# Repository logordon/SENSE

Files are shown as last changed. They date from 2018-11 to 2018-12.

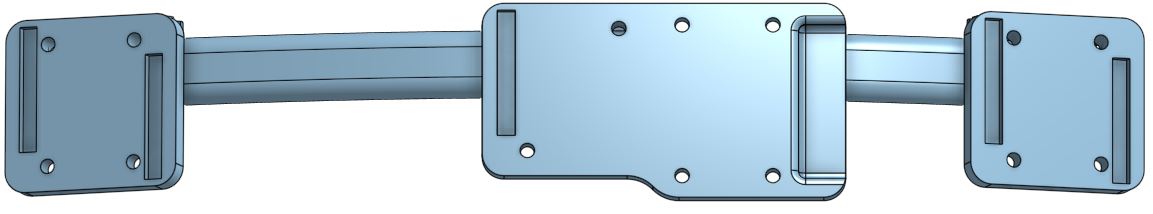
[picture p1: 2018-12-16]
Project Images/sensor_view_front.JPG

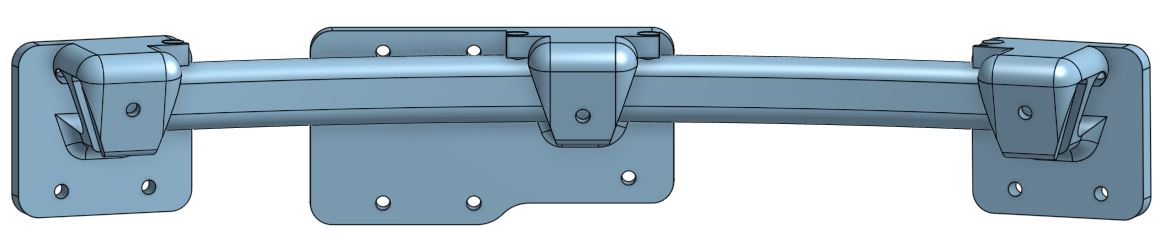
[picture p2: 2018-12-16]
Project Images/sensor_view_back.JPG

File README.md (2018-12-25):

# SENSE: Modernizing Blind Navigational Tools
Sense Glasses

# Welcome
Welcome and thank you for checking out _Project SENSE_. For more information on how this project was done **please visit the project [Wiki](https://github.com/logordon/SENSE/wiki)**. 

_Thank you and happy prototyping_ - Gordon Lo

# Project Overview Documents
**SENSE** was the 2018 Fall Northeastern Capstone 2nd place winner. Listed below are documents that will give you an overview of what _Project SENSE_ is about.
* [Project Presentation](https://github.com/logordon/SENSE/blob/master/Presentation%20Documents/SENSE%20Final%20Presentation.pdf)
* [Abstract](https://github.com/logordon/SENSE/blob/master/Presentation%20Documents/Abstract.pdf)

# Last Update
December 24, 2018 - Gordon Lo

# Special Thanks
Special thanks to [Arjun Vinod](https://github.com/arjun7965) for his extensive knowledge on hardware and software integration and my good friend Lek Kai Ming for modeling.

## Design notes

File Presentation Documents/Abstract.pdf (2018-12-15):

### SENSE: Modern Navigational Tools for the Blind

Team Members: Gordon Lo, Dixon Jin, Devin Touba, Imtiaz Hssan, Branden Bielot Advisor: Professor Bahram Shafai

Abstract
There has still not been any major technological advancement that comes remotely close to replacing the cane blind people use to interact with the world around them. Many of the modern blind aids that enable people to see, cater towards people with partial blindness and not to people who are totally blind. Data collected by the National Braille Press states that 0.45% or 1.5M of the US population are blind and thus SENSE aims to cater towards the needs of the totally blind and modernize the tools they use to navigate and interact with the world around them.

Two-devices: the SENSE glasses and the SENSE belt, capture and interpret data collected from the ultrasonic sensors and output haptic and audio feedback based on proximity to an obstacle. Utilizing a non-invasive technique called sensory substitution, we can bypass the loss of a sense (sight) by feeding its information through another channel (audio and touch). Leveraging this technique, we developed a low-cost vibratory belt and bone conducting audio glasses to allow blind people to perceive spatial awareness through small vibrations on their waist and audio alerts from bone conduction headphones.

Both SENSE devices compute and process data through individual raspberry pi zeroes. The SENSE glasses algorithm is designed based on the assumption that we dynamically scan areas of interest before and after sensing an obstacle. 3 ultrasonic sensors mounted on a pair of glasses gives the user free range to scan 3 meters ahead wherever they think may be an obstacle based on their instincts and other senses. Sensors on all SENSE devices are able to constantly and simultaneously take readings at the same time. This built-in functionality enables us to further divide the combined 75° sensor arc, into 5 smaller subsections: left, center-left, center, center-right and right. Depending on where the object within the 75° arc, audio cues will tell the user which sector the obstacle is in and how far away the obstacle is. Since our sensors are accurate till 3 meters, 3 beeps will represent 1 meter, 2 beeps will represent 2 meters and 1 beep will represent 1 meter. The glasses will output “center-left, beep, beep” when an obstacle is 2 meters away and in the center-left sector.

The SENSE belt, on the other hand, supplements the glasses by acting as a stationary 180° frontal guard that constantly scans for obstacles. Sensors are designed to point at a 30° downward angle to not only scan for obstacles at waist height but also sudden changes in elevation, such as stairs. With two sensors covering the outer sides, 270° and 90°, and another two sensors facing 315° and 45°, the SENSE belt guards againsts obstacles and changes in elevation within the user’s front facing 180° arc.

The SENSE system mimics how we perceive sight and movement. When utilized in conjunction with one another, the SENSE belt and glasses provides a full frontal obstacle avoidance system that allows blind people to scan and probe areas around them. With more research into more precise sensors and improvements to our algorithm, the SENSE system will replace the use of a cane.

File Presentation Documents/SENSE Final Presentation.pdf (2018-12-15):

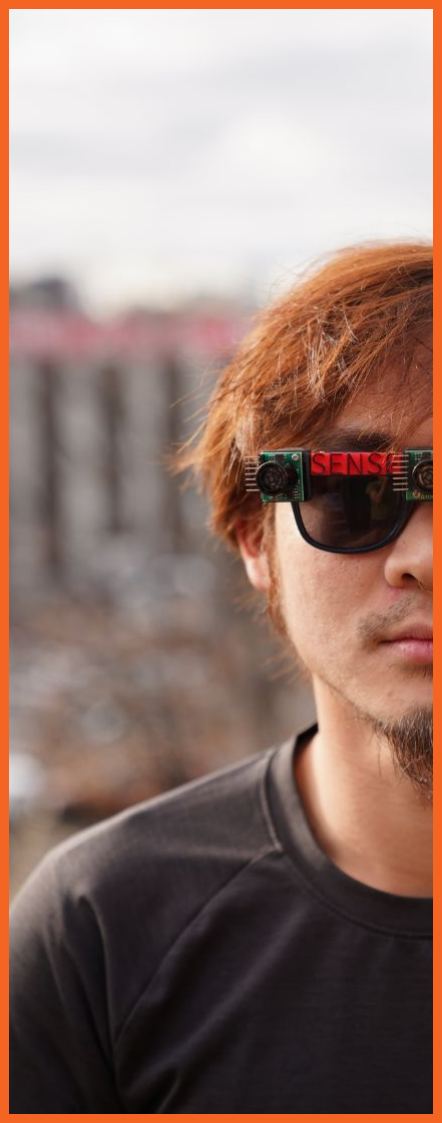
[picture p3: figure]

# SENSE:

# Modern Blind Navigation System

# EECE 4792 Capstone 2 Advisor: Bahram Shafai

# Gordon Lo, Dixon Jin, Devin Touba, Imtiaz Hssan, Branden Beilot

# SENSE Team

Gordon Lo | Dixon Jin | Devin Touba | Imtiaz Hssan | Branden Beilot
CE ● SENSE CAD & Design ● Manufacturing ● Circuitry ● SENSE Glasses | CE/CS
| ● Computer Vision ● Optical Character Recognition ● Text-to-Speech | CE
| | ● SENSE Belt ● Object Detection ● Elevation Change Recognition | CE
| | | ● SENSE Belt ● Object Detection ● Elevation Change Recognition | ECE
| | | | ● SENSE Belt ● Manufacturing ● Circuitry ● Object Detection

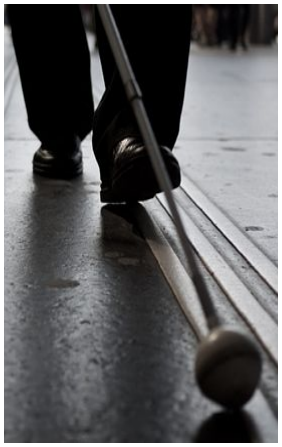
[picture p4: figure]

# The Space

# - 1.5M (0.45% of the US population) - 45M blind people worldwide (7B population) - 90% total blindness of those who are visually impaired in developing countries - 500,000 children become blind every year - 75M by 2020 blind

# Brian MacDonald

# -President of National Braille Press

# The Need

# - 3 events to which blindness occurs:

## - Birth defect - Disease - Traumatic event or accident

# - How do we…

## - Accelerate the learning curve of blind navigational tools - Bring confidence and normality

# - How can we create a tool that…

## - Blind people will make use of everyday - Assist blind people with obstacle avoidance and spatial orientation

# Competitors

- New tech advancements build off of existing tools i.e.

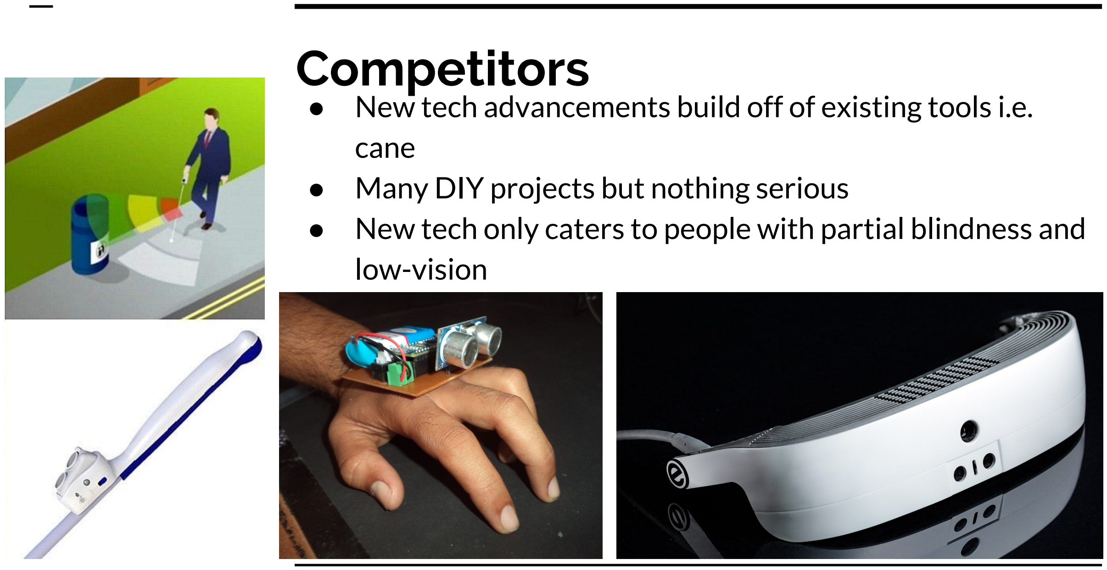
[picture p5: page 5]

# cane - Many DIY projects but nothing serious - New tech only caters to people with partial blindness and low-vision

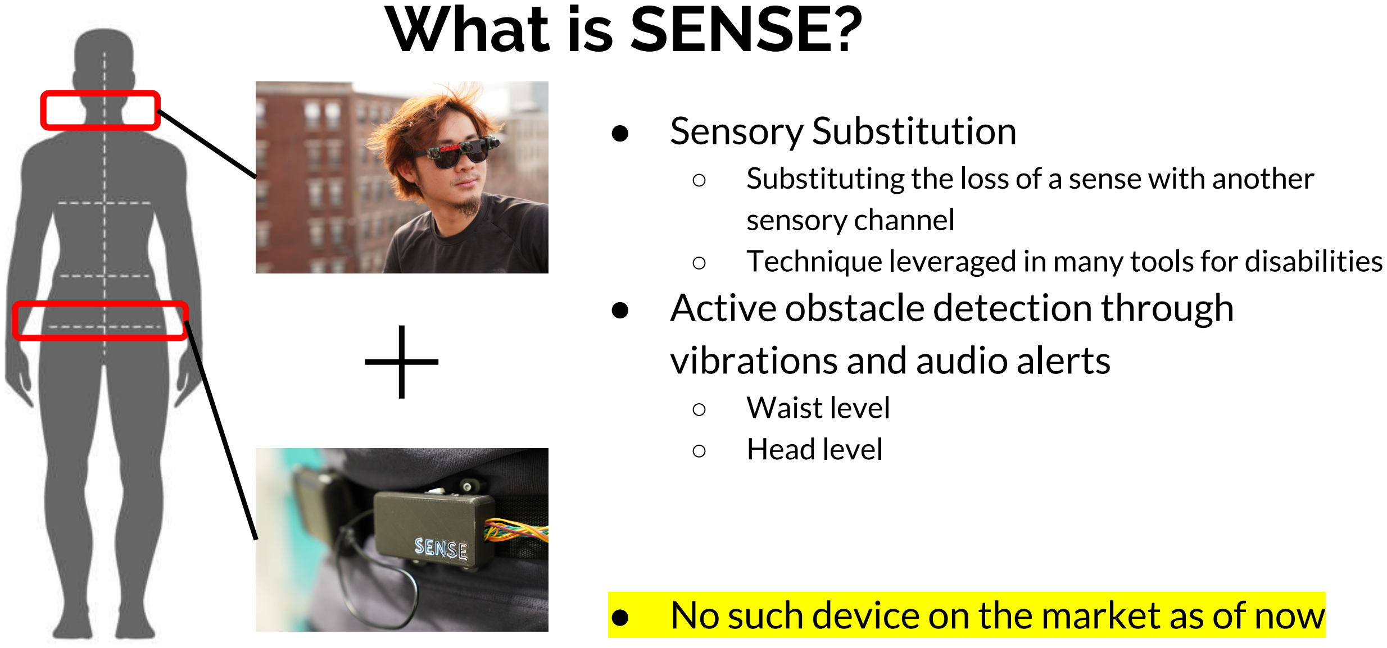
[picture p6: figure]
What is SENSE?; ● Sensory Substitution; sensory channel; ● Active obstacle detection through vibrations and audio alerts; ○ Waist level ○ Head level

## - Substituting the loss of a sense with another

## - Technique leveraged in many tools for disabilities

# - No such device on the market as of now

# Design Formulation

# - Modular design - Sleek design - Comfortable - Cheap and easy to manufacture

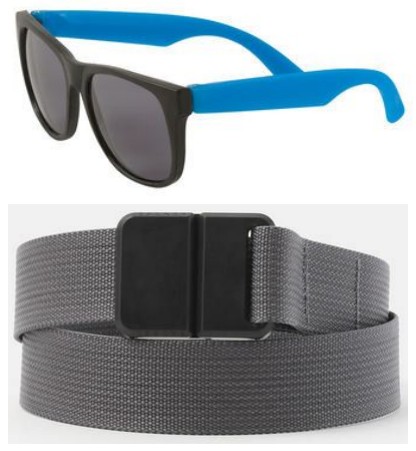
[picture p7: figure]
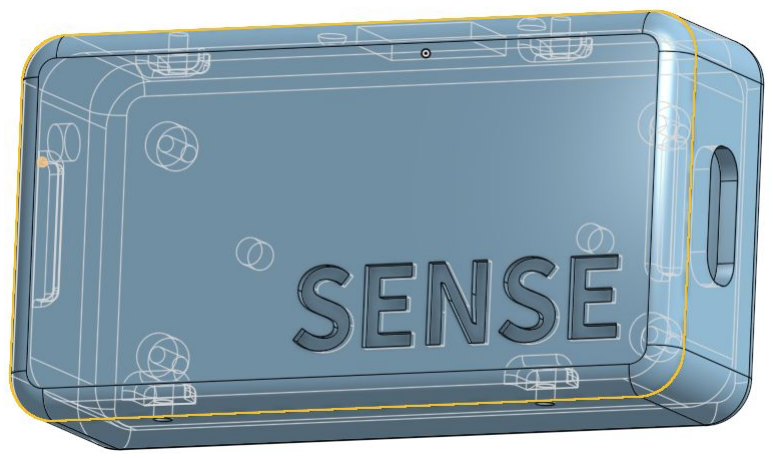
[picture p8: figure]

# SENSE

# Design Specifications: Glasses

Aspect | Specification | Justification
Function | 1 ON/OFF button | Easy to use
Cost | Cheap to manufacture, 3D printable parts | Tools for the disabled are always too expensive
Ergonomics | Sleek design and comfortable to wear | Wearables need to be comfortable or they will not be used
Materials | Light and durable material | Shockproof and waterproof
Aesthetics | Must be vibrant colored | People on the street need to tell if someone is blind
Function | Bone conduction headphones | Minimized hindrance on existing hearing sense
Design | Modular design, attachable to generic sunglasses frames | Modular design allows for quick changes if any part is damaged or broken
Function | Push button for RPI camera triggering | Single push for triggering text-to-speech

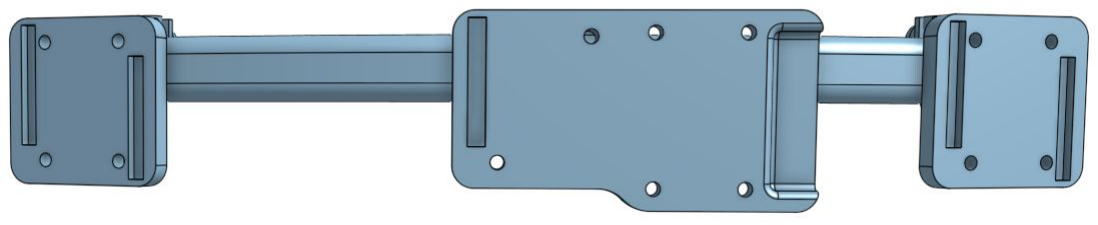
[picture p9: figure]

# Design and CAD

No. | Name | No. Pieces | Description
1 | Left Mount | 1 | Left sensor and glasses frame mount

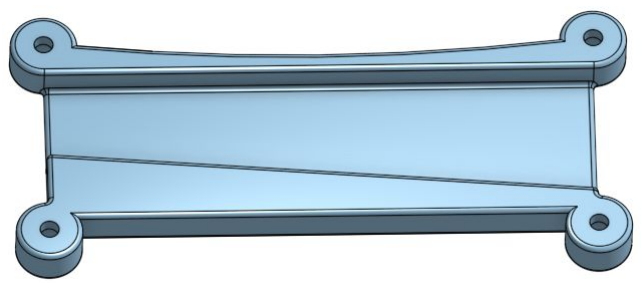
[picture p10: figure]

2 | Middle Mount | 1 | Middle sensor and glasses frame mount
3 | Right Mount | 1 | Right sensor and glasses frame mount
4 | Connector Rods | 2 | Bridges the sensors together and creates a curvature for the sensors

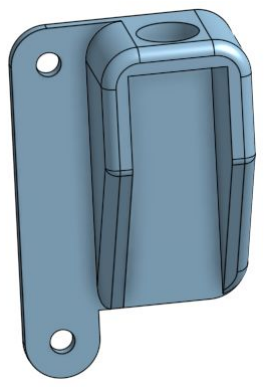
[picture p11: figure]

5 | RPI Zero Base | 1 | Mounts RPI Zero to glasses frame
6 | RPI Zero Frame | 1 | Frame for ADC and button
7 | Push Button Frame | 1 | Holds push button
9 | Power Plug Frame | 1 | Power connector

# More Design and CAD

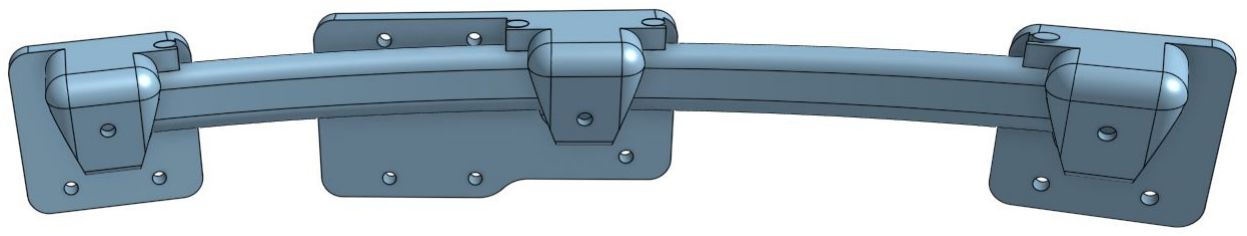
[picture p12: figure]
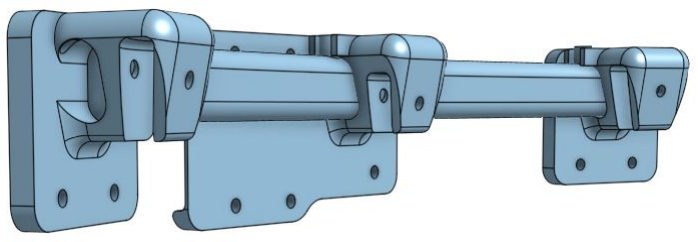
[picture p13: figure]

# Electronic Schematics

# - Ultrasonic Sensors

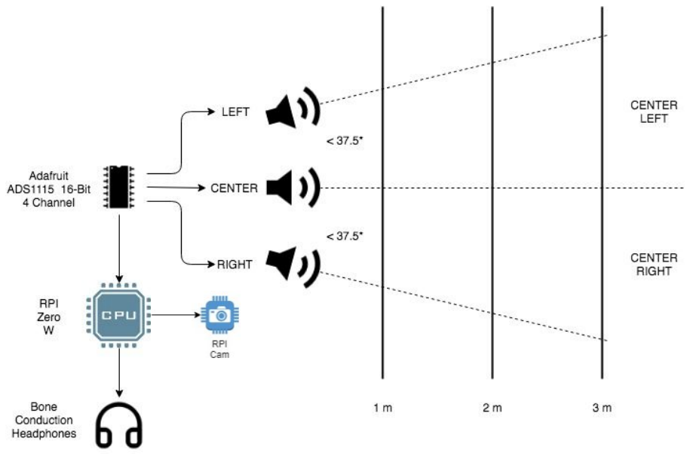
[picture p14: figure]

## - Max range 6.45m - Accurate range up to 3m

# - ADC

## - Enables simultaneous and continuous reading of sensors

# - RPI Zero W

## - Powerful chip for computations - Small form factor

# - RPI Camera

## - 3280 x 2464 px photo resolution - 1080p30, 720p60, 640x480p90 video resolution - Small form factor

# Functionality: Sensors

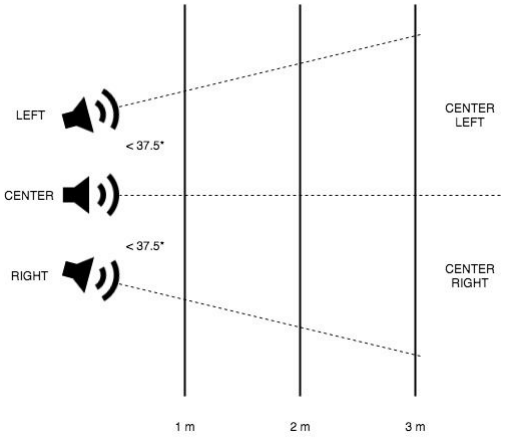
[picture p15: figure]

# - Audio Alerts

## - 3 beeps = 1 m close - 2 beeps = 2 m near - 1 beeps = 3 m far

# - Sector Location

## - Left - Center-left - Center - Center-right - Right

- Bone conduction headset (https://www.webopedia.com/TERM/B/bone-conduction-headphones.html)

## - Background alerts - Unhindered instincts

# Functionality: RPI Camera

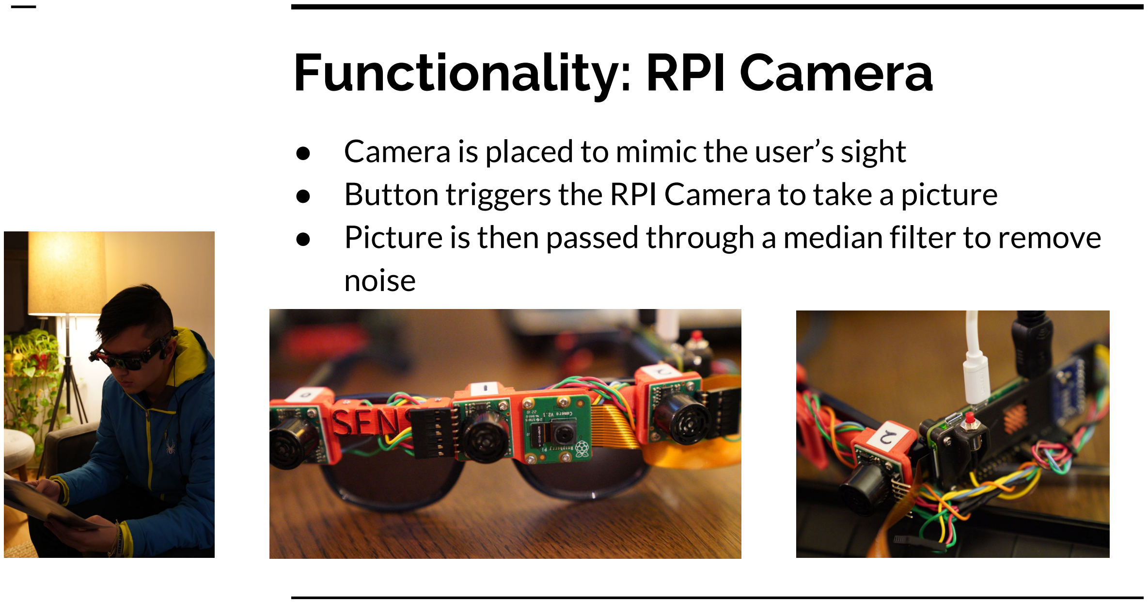
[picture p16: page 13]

# - Camera is placed to mimic the user’s sight - Button triggers the RPI Camera to take a picture - Picture is then passed through a median filter to remove noise

# RPI Camera

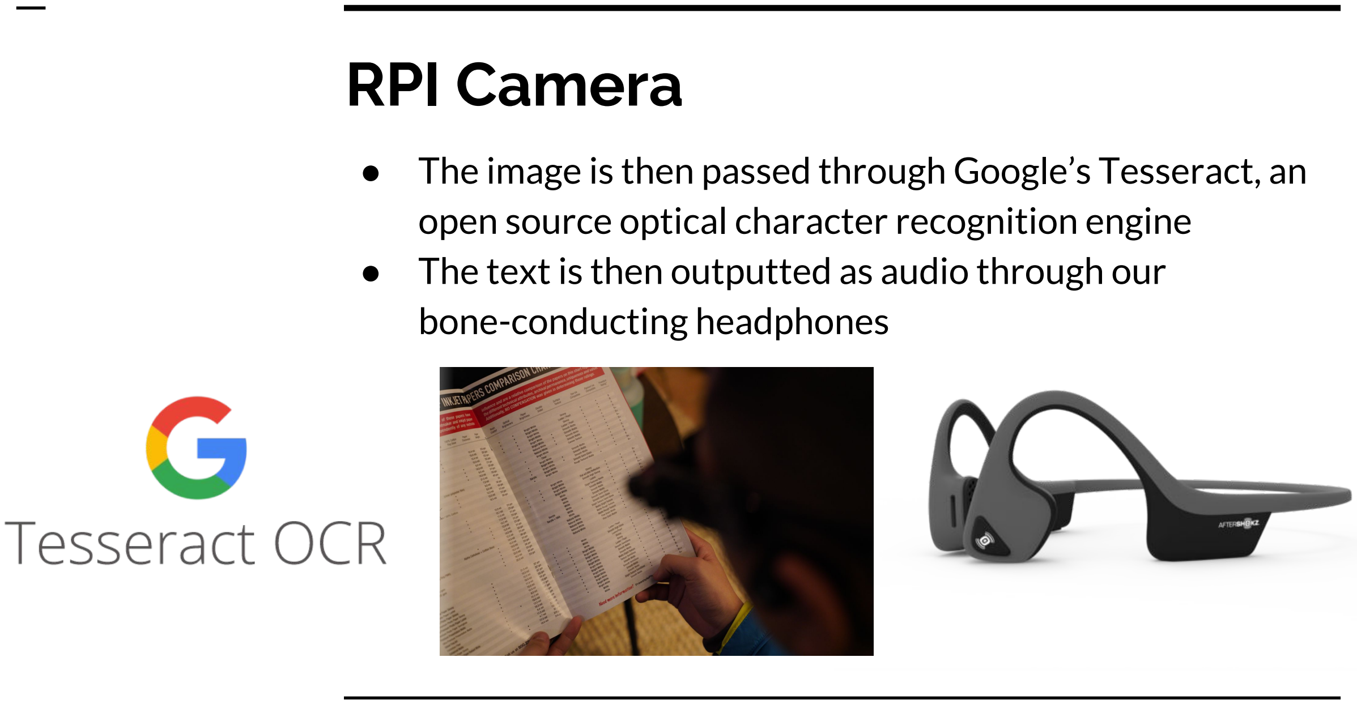
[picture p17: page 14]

# - The image is then passed through Google’s Tesseract, an open source optical character recognition engine - The text is then outputted as audio through our bone-conducting headphones

# BOM (Glasses Prototype)

Item | No. | Cost ($/Unit)
RPI Zero W | 1 | 10
Adafruit ADC ADS1115 16-Bit 4 Channel | 1 | 14.95
Maxbotix LV-MaxSonar EZ3 | 3 | 24.95
Sunglasses | 1 | 0 (promotional booth)
3D Printing Parts | 8 Pieces | (Shapeways ~ 45)
XT30 Connectors | 1 | 2
RPI Camera | 1 | 24.90
Treks Bone Conduction Headset | 1 Total | 80 206.7 + ~45 = $251.7

# SENSE Glasses

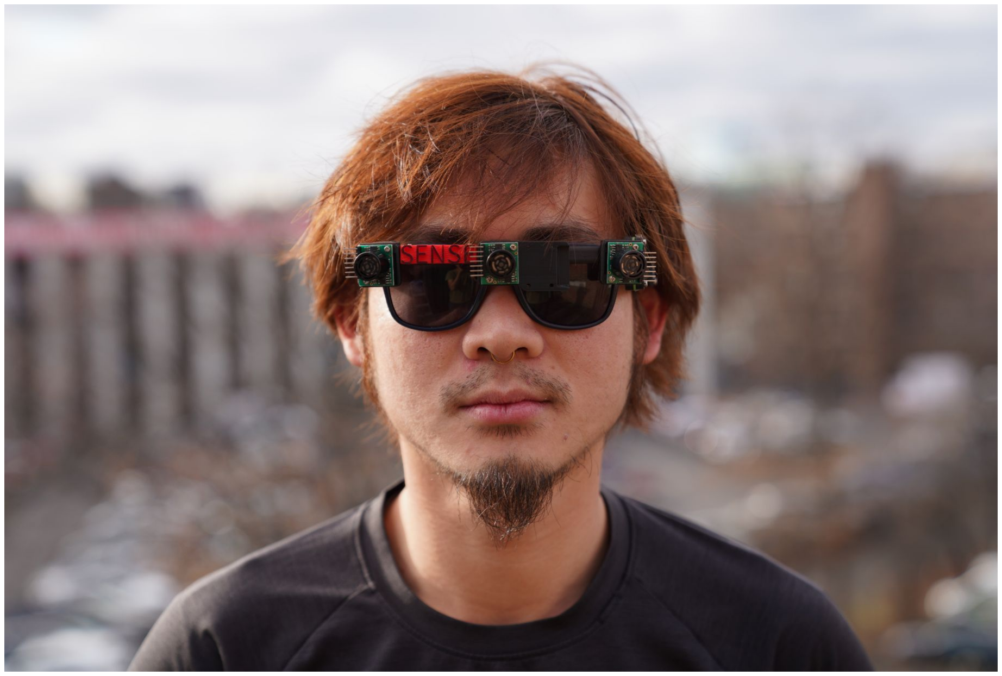
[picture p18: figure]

## - 3 x Ultrasonic Sensors - 75° Active Obstacle Detect - Bone conduction headphones for audio alerts - Sleek and comfortable design - Usable by people with hearing loss and damaged eardrums - Text-to-speech

# Design Specifications: Belt

Aspect | Specification | Justification
Function | 1 ON/OFF Button | Easy to use
Material | Magnetic belt buckle | Easy to put on/take off
Material | Custom 3D printed parts | Sturdy and made to our needs
Design | Modular design | Easy for user to distinguish which sensor is causing which response
Cost | Cheap to manufacture, 3D printed parts | Tools for the blind tend to be too expensive

# Design and CAD

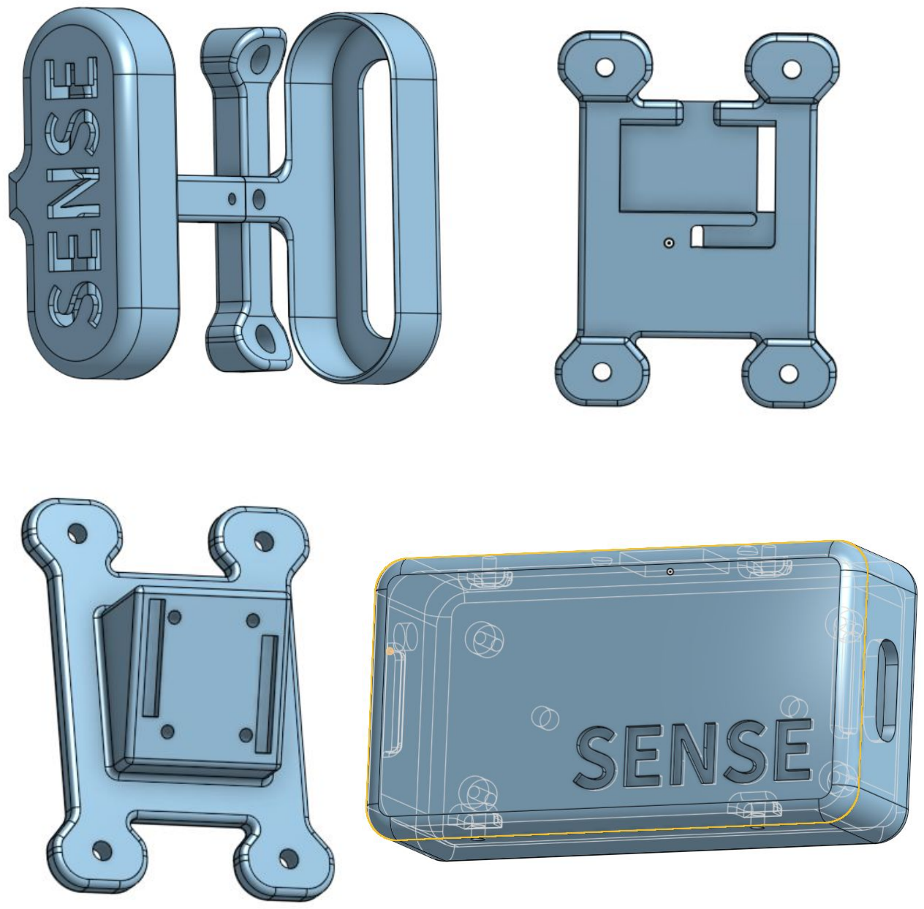
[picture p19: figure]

No. | Name | No. Pieces

Description

1 | Battery Pack Front Left Mount | 1 | Holds left side of battery pack. Has logo etched into side.
2 | Battery Pack Front Right Mount | 1 | Holds right side. Cutouts made for power chords to Pi.
3 | Battery Pack Back Mount | 2 | Holds other battery pack mounts to the belt
4 | Pi Casing | 1 | Holds the Raspberry Pi Zero and ADC
5 | Pi Cover | 1 | Covers the Pi Casing
6 | Pi Back Mount | 2 | Holds the Pi Casing to the belt
7 | Sensor Mount | 4 | Holds the ultrasonic sensor
8 | Vibration Motor Mount | 4 | Attaches to the back of the Sensor Mount and holds the whole module together to the belt

# Electronics Schematics

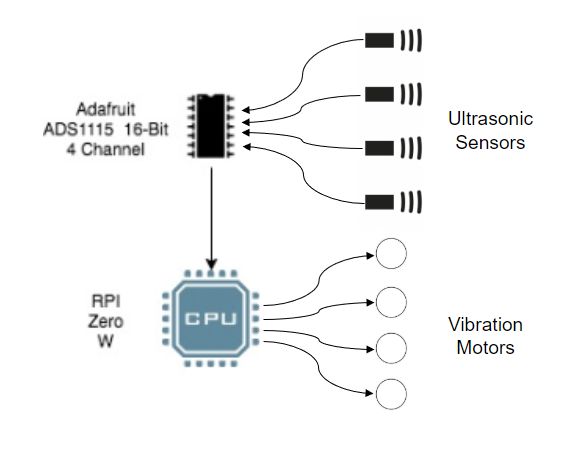
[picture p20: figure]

# - Ultrasonic Sensors

## - Max range 6.45m - Accurate range up to 3m

# - ADC

## - Enables simultaneous and continuous reading of sensors

# - RPI Zero W

## - Powerful chip for computations - Small form factor

# - Vibration Motors

## - Simple feedback for the user

# Simple, Easy, and Ready to Use

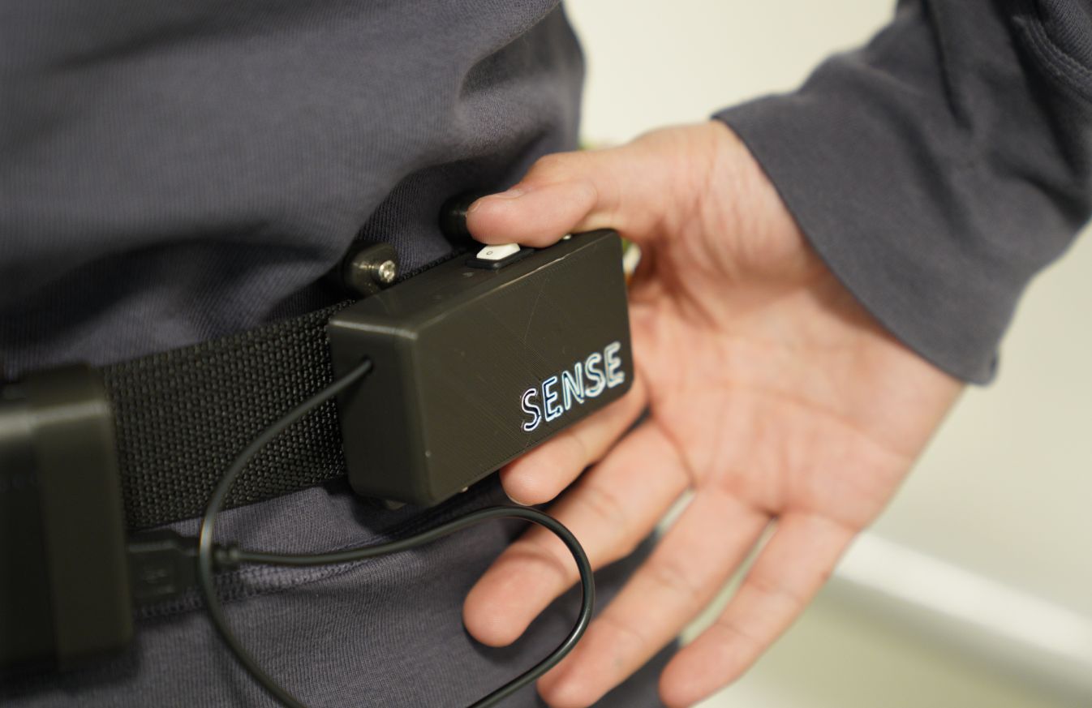
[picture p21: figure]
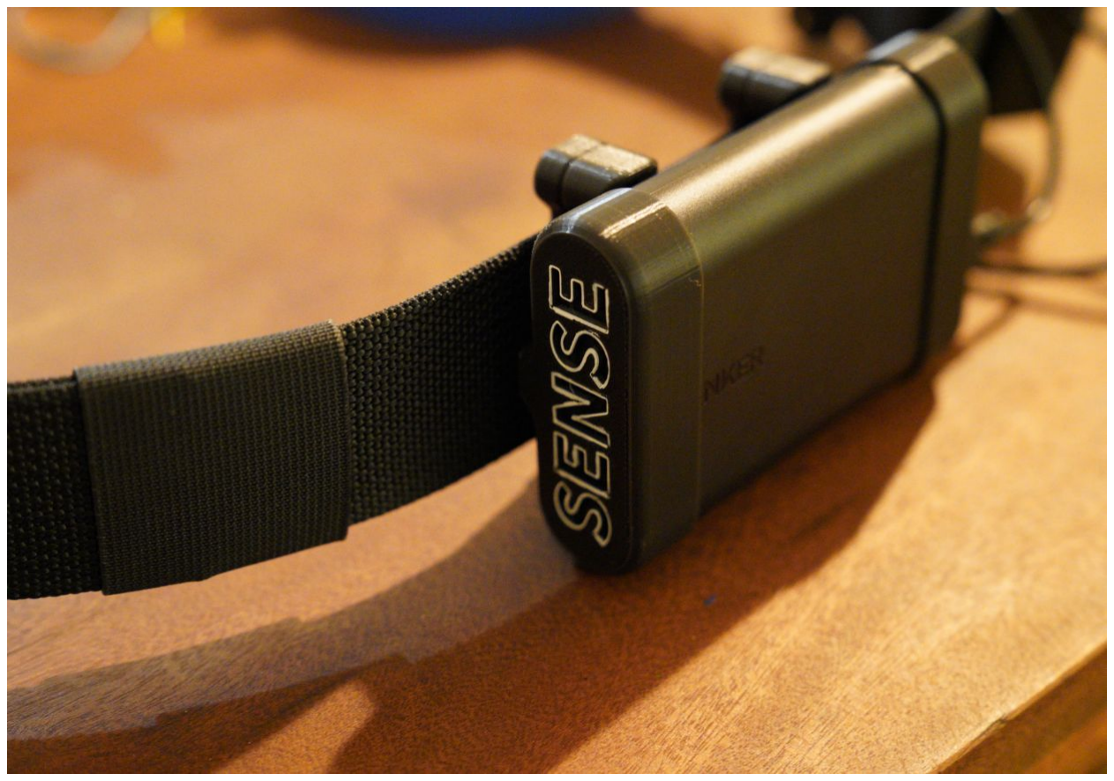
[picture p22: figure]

# Easy access for users

# Sleek design

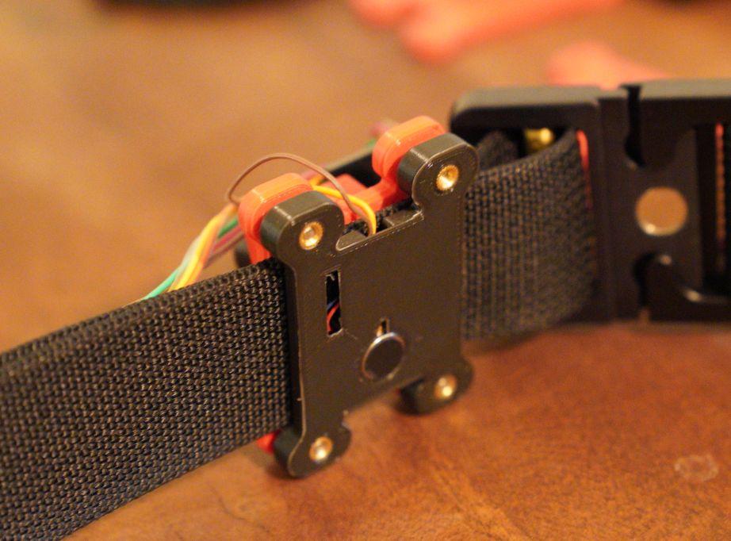
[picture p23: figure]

## So comfortable, you will not even notice!

# Functionality: Sensors

# - Vibration Feedback

## - Increasing frequency of vibration as obstacles

become closer.

## - Responses correlate to the sensor they are

detecting from.

# - Drop-Off Detection

## - Dedicated sensor to spotting surfaces which are further away than they should be

# BOM (Belt Prototype)

Item | No. | Cost ($/Unit)
RPI Zero W | 1 | 10
Adafruit ADC ADS1115 16-Bit 4 Channel | 1 | 14.95
Maxbotix LV-Maxsonar EZ3 | 4 | 24.95
3D Printing Parts | 16 Pieces | (Shapeways ~ 90)
Vibration Motors | 4 | 2
Belt | 1 | 30
| Total | $162.75 + ~90 = $252.75

# SENSE Belt

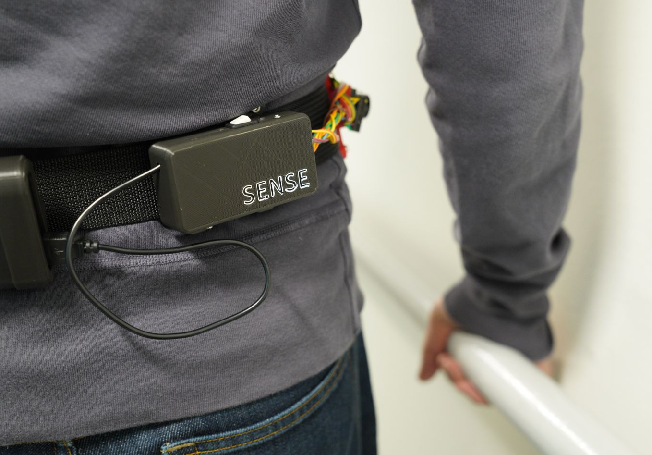
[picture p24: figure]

## - 4 x Ultrasonic Sensors - Continuous Radial Sensing - Vibration Motors for User Feedback - Quick and Easy to put on - Drop-Off in Elevation Detection

# Future Improvements

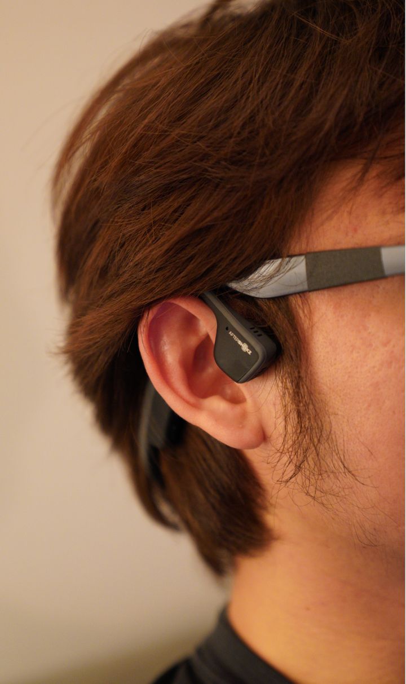
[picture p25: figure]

# - Custom PCB board with all the necessary components

## - Smaller form factor and weight - Less wires - Working bluetooth

# - Water resistant - Stronger materials - More precise sensors - RPI Zero W bluetooth not functioning

## - Bluetooth bone conduction headphones unusable

# - Disability awareness designed

# DEMO + Q&A

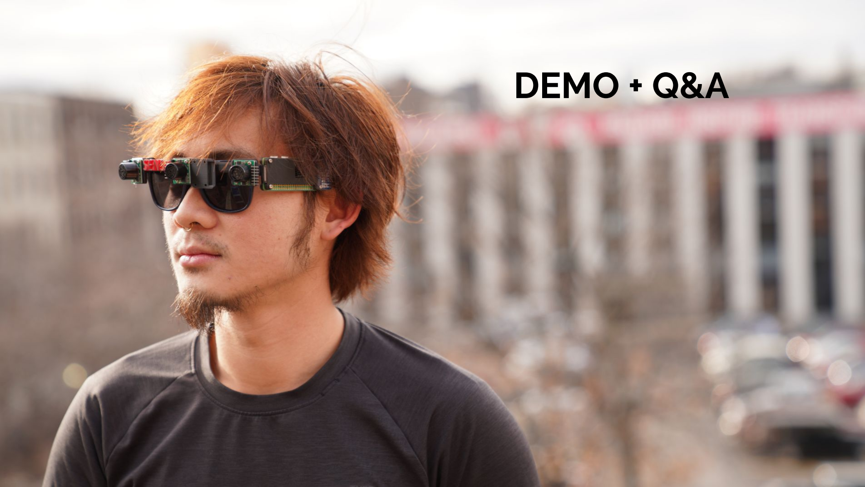
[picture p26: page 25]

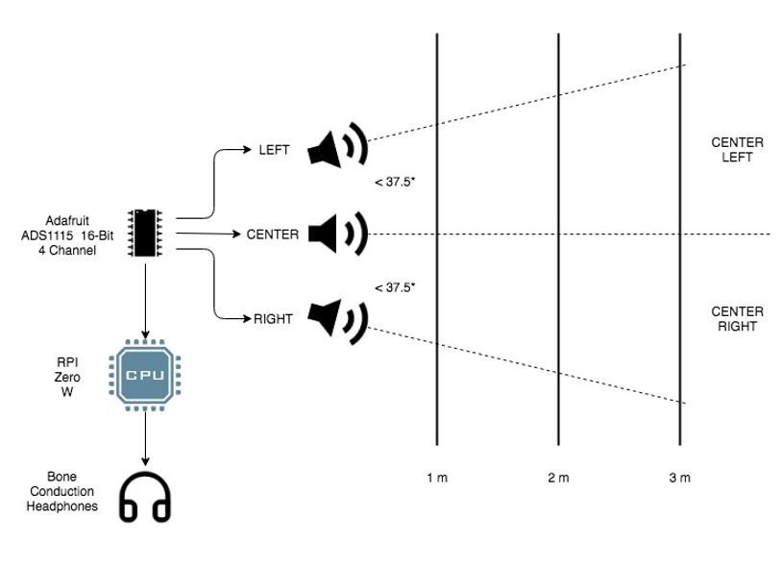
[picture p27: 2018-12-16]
Project Images/sense_schematic.JPG

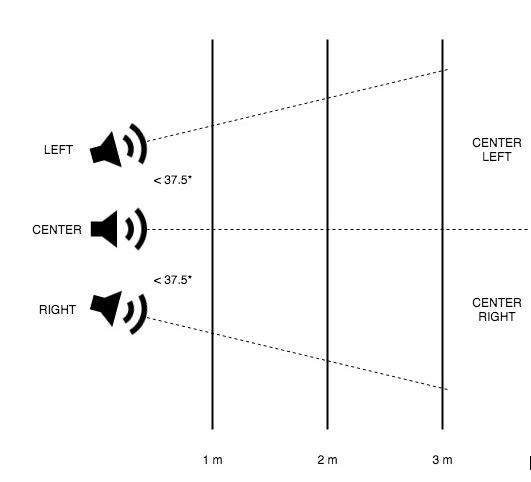
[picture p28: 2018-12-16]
Project Images/sense_functionality.JPG

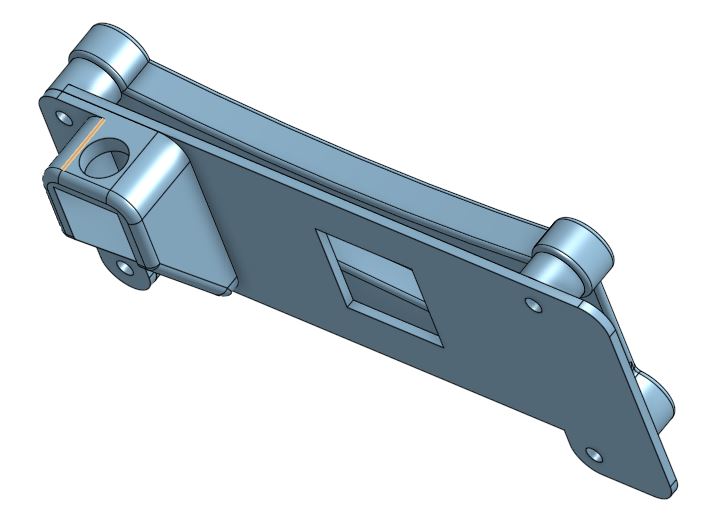
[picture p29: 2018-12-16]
Project Images/rpi_view_side.JPG

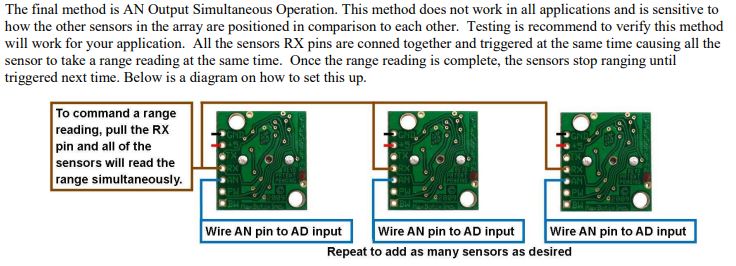
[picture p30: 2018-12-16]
Project Images/datasheet_simop.JPG

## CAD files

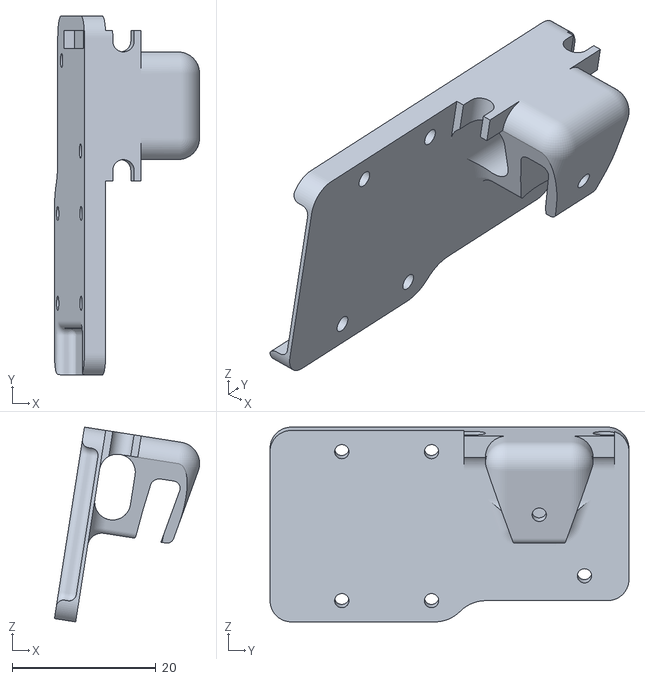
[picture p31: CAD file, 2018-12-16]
CAD Files/Glasses/Center R Mount.stl
20.2 x 50.0 x 27.1

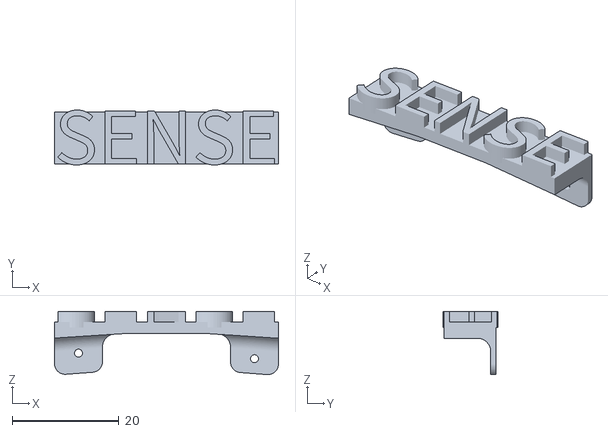
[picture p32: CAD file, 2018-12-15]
CAD Files/Glasses/SENSE Tag.stl
42.0 x 10.3 x 11.9

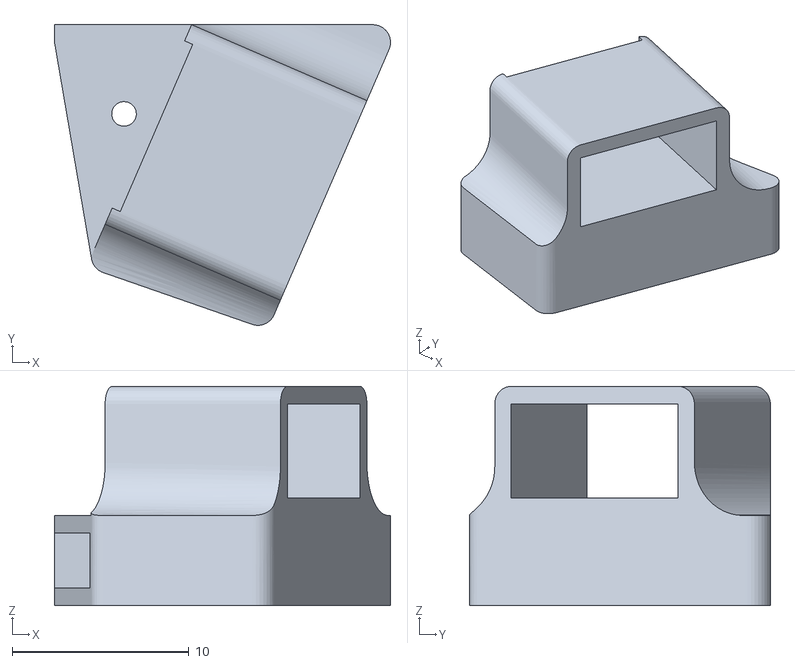
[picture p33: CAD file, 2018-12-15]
CAD Files/Glasses/Power Lead.stl
19.0 x 17.0 x 12.4

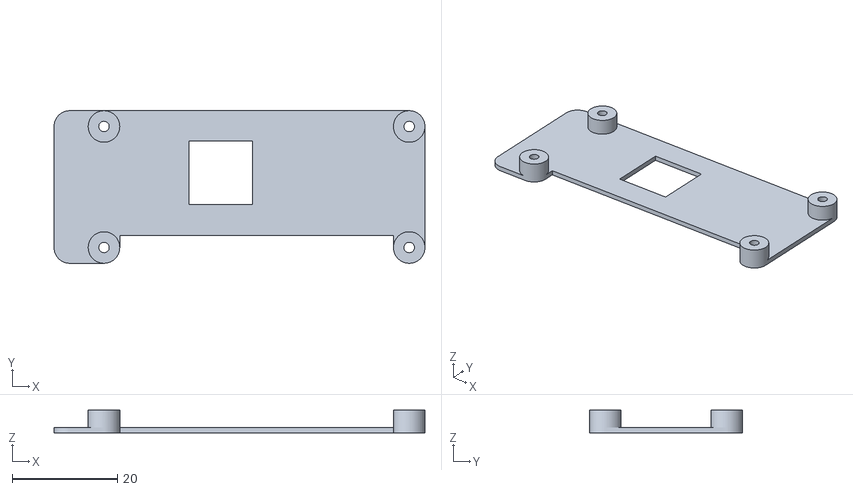
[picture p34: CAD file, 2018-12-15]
CAD Files/Glasses/Accessories Mount Base.stl
70.5 x 29.0 x 4.30

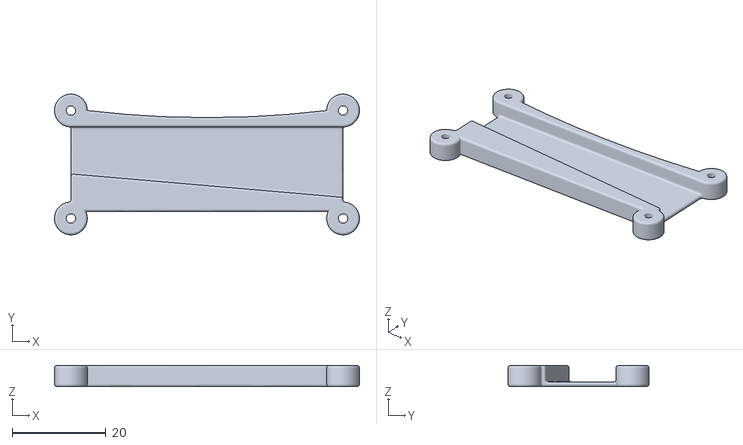
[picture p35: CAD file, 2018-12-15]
CAD Files/Glasses/RPi Zero W Backing.stl
65.0 x 30.0 x 4.50

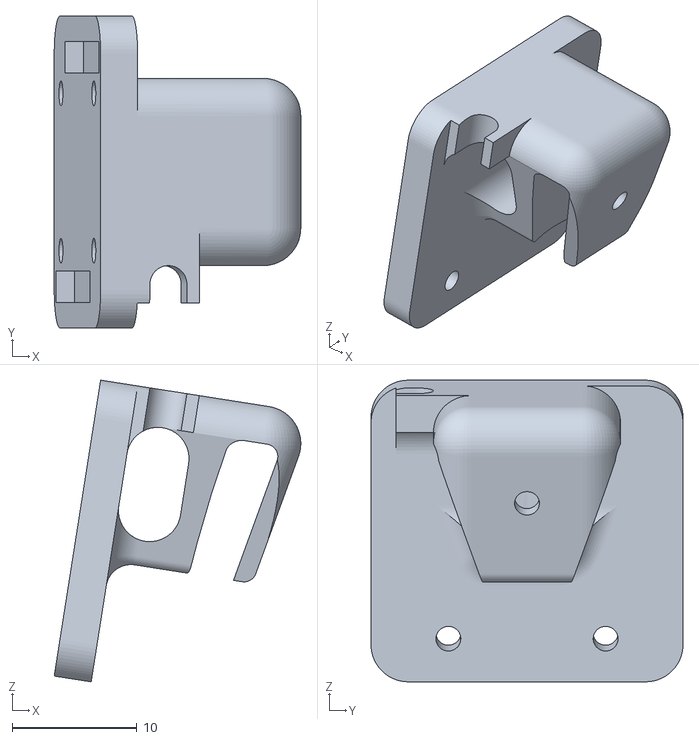
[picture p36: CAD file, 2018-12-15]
CAD Files/Glasses/Side Mount R.stl
19.8 x 25.0 x 24.2

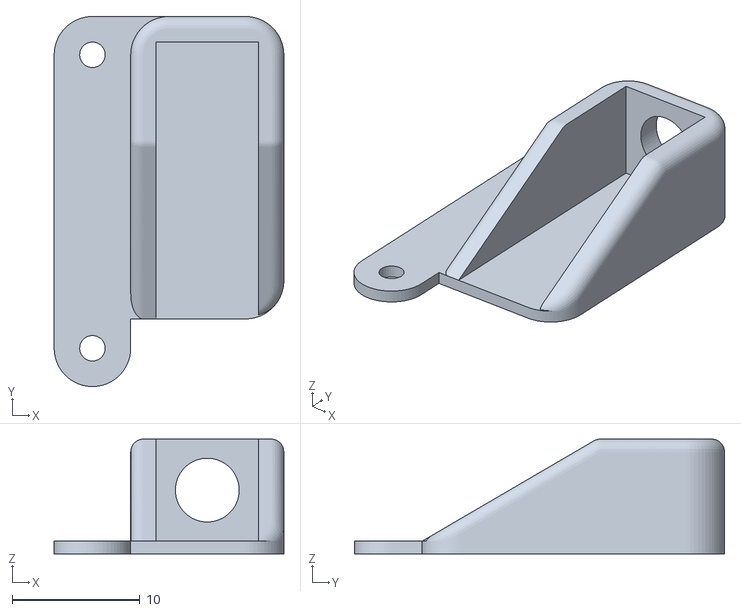
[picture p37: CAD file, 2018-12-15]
CAD Files/Glasses/Push Button Mount.stl
18.0 x 29.0 x 9.00

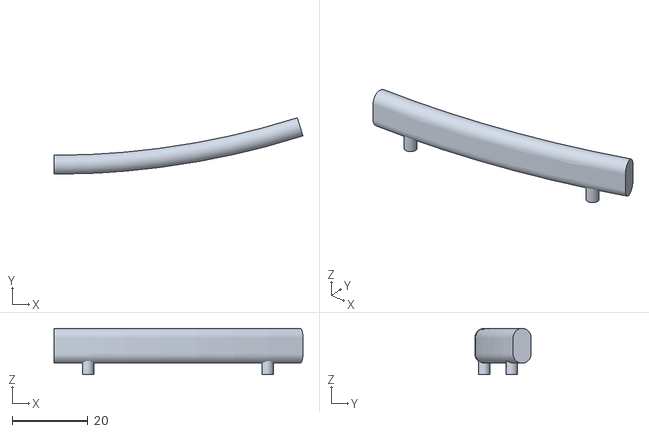
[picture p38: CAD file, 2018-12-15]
CAD Files/Glasses/Connecting Rod.stl
65.8 x 14.9 x 12.2

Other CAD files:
CAD Files/Glasses/Side Mount L.stl

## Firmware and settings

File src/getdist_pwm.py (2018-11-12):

import time
import RPi.GPIO as GPIO

# Use BCM GPIO references
# instead of physical pin numbers
GPIO.setmode(GPIO.BCM)

# Define GPIO to use on Pi
#GPIO_TRIGECHO = 15

print "Ultrasonic Measurement"

# Set pins as output and input
#GPIO.setup(GPIO_TRIGECHO,GPIO.OUT)  # Initial state as output
GPIO.setup(15,GPIO.OUT)
GPIO.setup(18,GPIO.OUT)

# Set trigger to False (Low)
#GPIO.output(GPIO_TRIGECHO, False)
GPIO.output(15,False)
GPIO.output(18,False)

def measure(GPIO_TRIGECHO):
  # This function measures a distance
  # Pulse the trigger/echo line to initiate a measurement
    GPIO.output(GPIO_TRIGECHO, True)
    time.sleep(0.00001)
    GPIO.output(GPIO_TRIGECHO, False)
  #ensure start time is set in case of very quick return
    start = time.time()

  # set line to input to check for start of echo response
    GPIO.setup(GPIO_TRIGECHO, GPIO.IN)
    while GPIO.input(GPIO_TRIGECHO)==0:
        start = time.time()

  # Wait for end of echo response
    while GPIO.input(GPIO_TRIGECHO)==1:
        stop = time.time()
  
    GPIO.setup(GPIO_TRIGECHO, GPIO.OUT)
    GPIO.output(GPIO_TRIGECHO, False)

    elapsed = stop-start
    distance = (elapsed * 34300)/2.0
    time.sleep(0.1)
    return distance

try:
    while True:
        distance1 = measure(15)
        print "  Distance1 : %.1f cm" % distance1
        time.sleep(0.5)
        distance2 = measure(18)
        print "  Distance2 : %.1f cm" % distance2
        time.sleep(0.5)

except KeyboardInterrupt:
    print("Stop")
    GPIO.cleanup()

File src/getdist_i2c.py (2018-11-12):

import time
import RPi.GPIO as GPIO
import Adafruit_ADS1x15
import subprocess
from subprocess import call

# Use BCM GPIO references
# instead of physical pin numbers
GPIO.setmode(GPIO.BCM)

# Define GPIO to use on Pi
GPIO_TRIGECHO = 14

print "Ultrasonic Measurement"

# Set pins as output and input
GPIO.setup(GPIO_TRIGECHO,GPIO.OUT)  # Initial state as output

# Set trigger to False (Low)
GPIO.output(GPIO_TRIGECHO, False)

#Create an ADS1115 instance
adc = Adafruit_ADS1x15.ADS1115()
GAIN=2

def measure():
  # This function measures a distance
  # Pulse the trigger/echo line to initiate a measurement
    GPIO.output(GPIO_TRIGECHO, True)
    time.sleep(0.00001)
    GPIO.output(GPIO_TRIGECHO, False)
    distance = [0]*3
    for i in range(3):
        distance[i] = adc.read_adc(i,gain=GAIN)

        # Distance in Inch (2^16 = 65535 for resolution)
        distance[i] = (distance[i] * 512)/65535

        # Distance in CM - 10 tolerance
        distance[i] = (distance[i] * 2.54)
        #print ("distance{0} = {1}".format(i,distance[i]))
    
    right = distance[0]
    center = distance[1]
    left = distance[2]
    
    if right < 100 and left < 100 and center <100:
        subprocess.call("aplay ~/straightahead_audio.wav", shell=True)
    elif left < 100  and right > 100 and center > 100:
        subprocess.call("aplay ~/left_audio.wav", shell=True)
    elif right < 100 and left > 100 and center > 100:
        subprocess.call("aplay ~/right_audio.wav", shell=True)
    elif left < 100 and center < 100 and right > 100:
        subprocess.call("aplay ~/centerleft_audio.wav", shell=True)
    elif right < 100 and center < 100 and left > 100:
        subprocess.call("aplay ~/centerright_audio.wav", shell=True)

try:
    while True:
        measure()
        time.sleep(2)

except KeyboardInterrupt:
    print("Stop")
    GPIO.cleanup()

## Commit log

2018-11-12 Reading sensor values through ADC (ADS1115)
2018-11-12 Reading sensors through RPI pwm
2018-12-15 CAD and Images Directories
    Added CAD files and project related images
    [Accessories Mount Base.stl, Connecting Rod.stl, Name Tag.stl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]
2018-12-15 Added working prototype sense script with rpi cam
2018-12-16 CAD Files
    Added center mount for sensor and rpi cam
    [Center R Mount.stl]
2018-12-16 CAD Images
    Added cad images and assembly images
2018-12-16 CAD SENSE Tag
    Added sense name tag
    [SENSE Tag.stl]
2018-12-16 Wiring Schematic Image
    Added wiring schematic image
2018-12-16 Simultaneous Operation Data Sheet
    Added image of simultaneous operation of ultrasonic sensors
